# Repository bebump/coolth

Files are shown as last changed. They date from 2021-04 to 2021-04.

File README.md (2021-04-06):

# Bebump Coolth fan controller

Bebump Coolth is a Windows utility that can dynamically control 4 fans
connected to an Arduino Nano.

System diagram

The code and build instructions for the Arduino part are also shared in this
repository. That includes a PCB and 3D printable enclosure if you want to make
it nice.

# Getting started

## Setting up your Arduino

Looking at the wiring diagram in the picture up top, you can quickly assemble
a working prototype using a breadboard.

You need to program the Nano board with the source file in
`arduino_nano/fan_controller.ino`.

If you want you can set persistent fan speeds stored on the Arduino by sending
the following command to it over serial.

    c 2 60 60 60 60

Where the last four `0 <=` integers <= `255`  are the duty cycles for the four
fans. During active operation the PC control software can dynamically overrule
these values. In case the PC software is not running, or communication fails
for more than 3 seconds the Arduino will go back to these persistent values.

## Installing the PC control software

You can download a Windows installer from the releases section. You have the
option to select automatic launch upon Windows startup from the installer.

After launching Bebump Coolth the program will scan the available COM ports
and find the programmed Arduino. It remembers the right COM port, so next time
it will open the same port first.

Everyting can be configured from the GUI and using the program should be
self-explanatory after a bit of experimentation.

The program must run to keep controlling your fans. If you minimize the
application it will become a background process and it will sit on the taskbar
notification area consuming next to no resources.

# Building the PC control software

## The standard way

* Visual Studio 2017 (C# and C++)
* CMake 3.15+

You can use these to build every binary artifact. You have to build
`temperature_reader/temperature_reader.sln` and the `bebump_coolth` target of
`CMakeLists.txt`.

## The completely automatic way

If you want, you can run `scripts/build_everything.py` which will probably do
everything for you from a completely clean checkout. In this case, you also
need

* Python 3.6+

Running the script file will ask you to specify the build output directory (or
use default). Then it will try to find your Visual Studio installation, and
CMake (should be available on your PATH), and then try to build everything.

Worked on my machine.

## Creating the installer

If you choose the automatic way, there will be a bunch of files in the build
output directory.

If you have 

* InnoSetup 6.1.2

you can double click and run the `coolth.iss` file from the build output
directory, press the green play button, and you will have your own installer.

# Building a nicer controller hardware

If you don't want a fire hazard lying around or inside your computer, you may
want to build a proper device with a PCB and 3D printed enclosure.

You can order a PCB by sending the files in `arduino_nano/gerber` to a PCB
manufacturer.

Fan controller PCB

You need to solder the folling components on the PCB.

* 4x Molex 47053-1000 connector
* 1x 5.08 mm PCB terminal block
* 2.54 mm pin headers for connecting the Arduino Nano

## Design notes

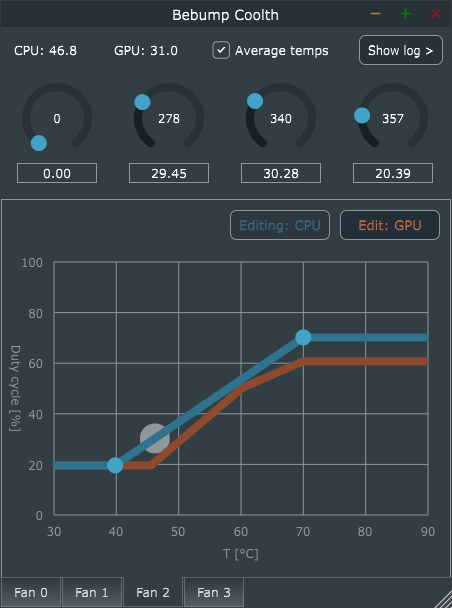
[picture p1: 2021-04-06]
docs/img/coolth_screenshot.png

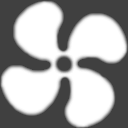
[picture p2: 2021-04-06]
resources/systray.png

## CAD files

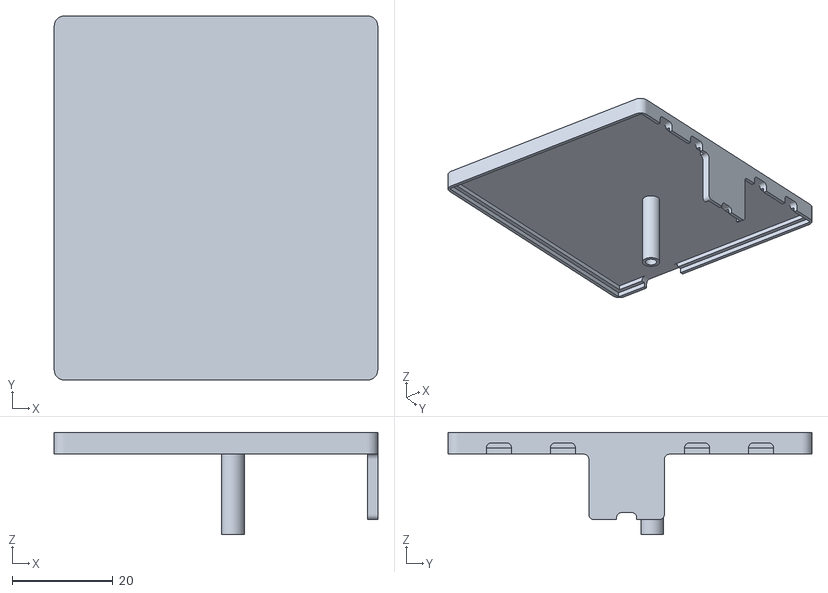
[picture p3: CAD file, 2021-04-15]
arduino_nano/enclosure/enclosure_top.stl
64.3 x 72.3 x 20.4

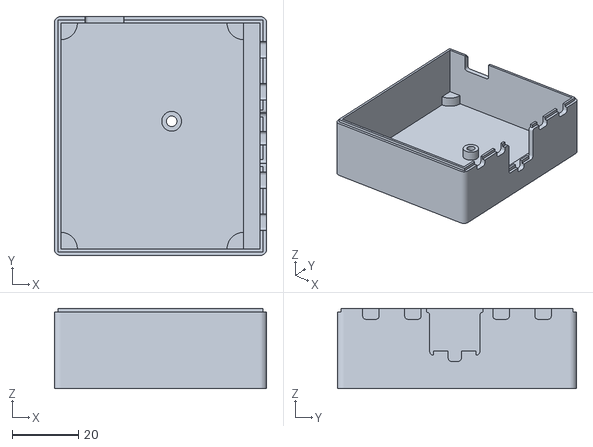
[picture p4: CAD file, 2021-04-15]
arduino_nano/enclosure/enclosure_bottom.stl
64.3 x 72.3 x 24.3

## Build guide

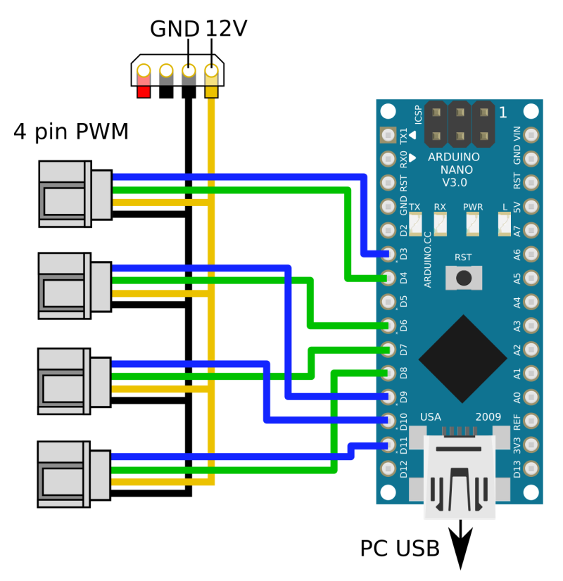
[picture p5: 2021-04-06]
docs/img/wiring_diagram.png

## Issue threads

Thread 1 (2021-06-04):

How to get CPU and GPU temperate data?

Ahmed-Mohiuddin-Shah, 2021-06-04:
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
The CPU and GPU temperature are not showing in the program,
Is there any solution to this?
I have three fans attached to an Arduino Nano.

bebump, 2021-06-04:
Hi Ahmed, I'll do my best to help you, but I'll need more information.

1. Please show me the contents of the log. Click the Log button, like below.
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
2. Did you build the software yourself, or did you install the release?

In any case, please go to

`C:\Users\[YOUR_USERNAME]\AppData\Local\Programs\Bebump Coolth`

and see if you see the file `temperature_reader.exe`. Double click and run it manually, and tell me what the output is.

Ahmed-Mohiuddin-Shah, 2021-06-04:
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

bebump, 2021-06-06:
Thanks for the info.

### New release for seeing at least GPU temps

I have created a new release 0.9.6 which will display and utilize your GPU temperature even if the CPU temperature cannot be read. You can use this to automate your fans based at least on your GPU temperature.

### Further investigation

The root cause of your problem is that `temperature_reader.exe` is unable to read your CPU's temperature. This could be because OpenHardwareMonitor, which is used under the hood, is unable to read the CPU temp.

What CPU model do you have?

You could also verify that this is truly the case by downloading and running Open Hardware Monitor on your machine, and sending me a screenshot like the first image on the following page.

https://openhardwaremonitor.org/

Bebump Coolth already comes with the latest released version of Open Hardware Monitor, so if you have an Intel 11 series CPU that could be a problem. But seeing the screenshot, maybe I can find a workaround or maybe switch to Libre Hardware Monitor.

Ahmed-Mohiuddin-Shah, 2021-06-06:
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
The software is reading the GPU temperature correctly now.
Only CPU temp is not being shown now.
I have installed and opened Open Hardware Monitor and it is detecting CPU Temperature correctly.
My System specs:
core i5 650
nvidia gtx 650
8gb ram
hp oem system

What else could be the problem?
Thanks for the quick responses.

bebump, 2021-06-06:
The screenshot was helpful. I can see you have reported CPU core temperatures, just not a CPU package temperature.

I released a new version (0.9.7) which will use the CPU Core 1 temperature in case there is no package temperature.

Ahmed-Mohiuddin-Shah, 2021-06-06:
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

It is now reading the temperature of the CPU but the CPU reading gets stuck at the reading it started with.
rest of the program is working correctly.

Sorry for late response I was out for work.

bebump, 2021-06-06:
Thank you for the feedback. I can see the issue, and hopefully I fixed it with release 0.9.8.

Ahmed-Mohiuddin-Shah, 2021-06-06:
.exe file is not available in 0.9.8 release

bebump, 2021-06-06:
The number of things that can go wrong. I added the file.

Ahmed-Mohiuddin-Shah, 2021-06-06:
1.   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
Yes! It is working now.
Thank you for helping me.

2.  If in the future if I have any issue should I post in this thread or start new issue?

3.  I like your software. it is very simple and easy to use. You should upload some videos of your software on YouTube. I am sure people will like it. I am making a PowerMac g5 mod case and I will be uploading videos of it so I will make sure to guide people towards your program. Developers like you should be given more recognition.

4. Just one more question is it possible to add HDD0 and HDD1?

bebump, 2021-06-07:
Thank you for the kind words. I'll be closing this issue, please open a new one for future, unrelated issues.

I'll keep the HDD0 feature request in mind, although I can't promise when I might be getting around to implementing it.

UMCURA, 2023-07-29:
Hello, I have problems with the temperature of the GPU, it appears from time to time, but most of the time it does not appear in the program and the operation is wrong. I only have a fan connected, I'm testing it. I have tested the 4 versions and the same problem. What could be happening?. Thank you so much.

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

Closed 2021-06-07.

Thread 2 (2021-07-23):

How to change PWM Frequency?

Ahmed-Mohiuddin-Shah, 2021-07-23:
Is there a way to change to PWM frequency so that my fans don`t make a whining noise.
At slow RPM they create a whining noise which goes away when they are at full speed.
Is there a way where I can change the PWM frequency through the Arduino sketch?

bebump, 2021-07-24:
The PWM frequency is determined by applying various dividers to the 16 MHz clock rate. You can change these divider values in the sketch.

It's worth noting that some of these dividers will also affect the time measurement, so it can mess with the RPM measurement functionality.

You can experiment with it though, just remember, that modifying some related dividers will make the software display incorrect RPM values, and there isn't an easy way around it. It won't affect the behavior of the fans though, so your fans will be controlled correctly, it will be just the displayed values that may be incorrect.

https://www.etechnophiles.com/how-to-change-the-pwm-frequency-of-arduino-nano/

E.g. adding the line `TCCR2B = TCCR2B & B11111000 | B00000001;` somewhere in the beginning of the sketch will raise some PWM frequencies to 31 kHz.

That's as much as I remember from years back. I am using high quality PWM fans which aren't affected by the PWM signal's frequency, because they generate the motor driving signals internally, so I just left things on default in the Arduino sketch.

Ahmed-Mohiuddin-Shah, 2021-07-25:
Thank you. The whine is gone.
I just added the following two line in the setup to change the PWM frequency for pins 3, 5, 6.

TCCR2B = TCCR2B & B11111000 | B00000001;
TCCR0B = TCCR0B & B11111000 | B00000001;

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

I am using pins 3, 5, 6 as those are the pins my fans are attached to. My fans are two wire DC fans so they whine with the default PWM.

If some one else is having Whining Issue and is using the default sketch and schematic then add the following two lines:

TCCR2B = TCCR2B & B11111000 | B00000001;
TCCR1B = TCCR1B & B11111000 | B00000001;

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

Thank you for your help.

Ahmed-Mohiuddin-Shah, 2021-07-27:
UPDATE:
The program was having trouble connecting to the Arduino after adding the lines.

I have now changed the location of the line and the problem is not occurring now.

I removed the following two line in the setup and added them in void loop() before the analogWrite to change the PWM frequency for pins 3, 5, 6.

TCCR2B = TCCR2B & B11111000 | B00000001;
TCCR0B = TCCR0B & B11111000 | B00000001;
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

If some one is using the default sketch and schematic then add the following two lines:

TCCR2B = TCCR2B & B11111000 | B00000001;
TCCR1B = TCCR1B & B11111000 | B00000001;
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

I will update in two days if there are any other issues. If there are none the i will close the issue.

Ahmed-Mohiuddin-Shah, 2021-08-03:
I had no issues. I am closing the issue.

Closed 2021-08-03.

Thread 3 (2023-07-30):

Errors in GPU temperatures.

UMCURA, 2023-07-30:
Hello, I have problems with the temperature of the GPU, it appears from time to time, but most of the time it does not appear in the program and the operation is wrong. I only have a fan connected, I'm testing it. I have tested the 4 versions and the same problem. What could be happening?. Thank you so much.

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

UMCURA, 2023-07-30:
News. Tested on another PC with a Xeon and same O.S. It works perfect. Great since that's where I want to install it. The only thing I see is that the 'Temperature_Reader.exe' gives the data without decimals, none. Maybe that's the problem on this other PC where I started testing it? It has an AMD Ryzen.

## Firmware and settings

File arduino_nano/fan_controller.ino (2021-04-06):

/*
Copyright 2016 Attila Szarvas

Licensed under the Apache License, Version 2.0 (the "License");
you may not use this file except in compliance with the License.
You may obtain a copy of the License at

    http://www.apache.org/licenses/LICENSE-2.0

Unless required by applicable law or agreed to in writing, software
distributed under the License is distributed on an "AS IS" BASIS,
WITHOUT WARRANTIES OR CONDITIONS OF ANY KIND, either express or implied.
See the License for the specific language governing permissions and
limitations under the License.
*/


#include <EEPROM.h>

const int kFan0PwmPin = 3;
const int kFan1PwmPin = 9;
const int kFan2PwmPin = 10;
const int kFan3PwmPin = 11;

const int kFan0RpmPin = 4;
const int kFan1RpmPin = 6;
const int kFan2RpmPin = 7;
const int kFan3RpmPin = 8;

void setup() {
  Serial.begin(19200);

  pinMode(kFan0RpmPin, INPUT_PULLUP); 
  pinMode(kFan1RpmPin, INPUT_PULLUP);
  pinMode(kFan2RpmPin, INPUT_PULLUP); 
  pinMode(kFan3RpmPin, INPUT_PULLUP);
}

void emptySerialBuffer() {
  while (Serial.available() > 0) {
    Serial.read();
  }
}

// Returns 1 if command is intercepted
//         0 otherwise
int ReadSerial(int* buffer, const unsigned int length) {
  while (Serial.available() > 0) {
    if (Serial.read() == 'c') {
      Serial.setTimeout(100);
      int i;
      for (i = 0; i < length; ++i) {
        buffer[i] = Serial.parseInt();
      }

      // We want to respond quickly to duty cycle commands
      // So if there is a long queue of such commands, we 
      // discard the old ones
      emptySerialBuffer();
      return 1;
    }
  }
  
  return 0;
}

// This affects the minimum measurable RPM
// Non-rotating fans will cause twice this much delay per reading
const unsigned long kPwmReadTimeout = 300000;

unsigned long ReadRpm(const int pin) {
  digitalWrite(pin, HIGH);
  delay(5);
  
  // Intel compliant PWM fans generate 2 pulses per cycle
  const unsigned long period_width = 60000000/2;
  unsigned long cycle_width = pulseIn(pin, LOW, kPwmReadTimeout) + pulseIn(pin, HIGH, kPwmReadTimeout);
  
  if (cycle_width == 0) {
    return 0;
  }
  
  return period_width / cycle_width;
}

int dutycycle_command_age = 0;
int fan_0_dutycycle;
int fan_1_dutycycle;
int fan_2_dutycycle;
int fan_3_dutycycle;

void loop() {
  dutycycle_command_age += 1;
  
  const int kCommandLength = 5;
  int command[kCommandLength];
  
  const int kCommandSetDutycycle = 1;
  const int kCommandSetDefaultDutycycle = 2;
  
  unsigned int rpm0, rpm1, rpm2, rpm3;

  rpm0 = ReadRpm(kFan0RpmPin);
  rpm1 = ReadRpm(kFan1RpmPin);
  rpm2 = ReadRpm(kFan2RpmPin);
  rpm3 = ReadRpm(kFan3RpmPin);
      
  Serial.print(rpm0);
  Serial.print(" ");
  Serial.print(rpm1);
  Serial.print(" ");
  Serial.print(rpm2);
  Serial.print(" ");
  Serial.print(rpm3);
  Serial.print(" ");
  Serial.print(fan_0_dutycycle);
  Serial.print(" ");
  Serial.print(fan_1_dutycycle);
  Serial.print(" ");
  Serial.print(fan_2_dutycycle);
  Serial.print(" ");
  Serial.println(fan_3_dutycycle);

  if (ReadSerial(command, kCommandLength)) {
    switch (command[0]) {
      case kCommandSetDutycycle:
        dutycycle_command_age = 0;
        fan_0_dutycycle = command[1];
        fan_1_dutycycle = command[2];
        fan_2_dutycycle = command[3];
        fan_3_dutycycle = command[4];
        break;
        
      case kCommandSetDefaultDutycycle:
        EEPROM.write(0, command[1]);
        EEPROM.write(1, command[2]);
        EEPROM.write(2, command[3]);
        EEPROM.write(3, command[4]);
        break;
    }
  }
  
  if (dutycycle_command_age > 10) {
    fan_0_dutycycle = EEPROM.read(0);
    fan_1_dutycycle = EEPROM.read(1);
    fan_2_dutycycle = EEPROM.read(2);
    fan_3_dutycycle = EEPROM.read(3);
  }
  
  analogWrite(kFan0PwmPin, fan_0_dutycycle);
  analogWrite(kFan1PwmPin, fan_1_dutycycle);
  analogWrite(kFan2PwmPin, fan_2_dutycycle);
  analogWrite(kFan3PwmPin, fan_3_dutycycle);

  delay(200);
}

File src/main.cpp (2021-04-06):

/*
Copyright (c) 2021 Attila Szarvas <attila.szarvas@gmail.com>

All rights reserved. Use of this source code is governed by the 3-Clause BSD
License that can be found in the LICENSE file.
*/

#include "main_component.h"

#include "BinaryData.h"

class GuiAppApplication : public juce::JUCEApplication {
 public:
  GuiAppApplication() = default;

  const juce::String getApplicationName() override {
    return JUCE_APPLICATION_NAME_STRING;
  }

  const juce::String getApplicationVersion() override {
    return JUCE_APPLICATION_VERSION_STRING;
  }

  bool moreThanOneInstanceAllowed() override { return false; }

  void initialise(const juce::String& command_line) override {
    juce::ignoreUnused(command_line);
    main_window = std::make_unique<MainWindow>(getApplicationName() + " " +
                                               getApplicationVersion());
  }

  void shutdown() override { main_window = nullptr; }

  void systemRequestedQuit() override {
    // This is called when the app is being asked to quit: you can ignore this
    // request and let the app carry on running, or call quit() to allow the app
    // to close.
    quit();
  }

  void anotherInstanceStarted(const juce::String& command_line) override {
    // When another instance of the app is launched while this one is running,
    // this method is invoked, and the command_line parameter tells you what
    // the other instance's command-line arguments were.
    juce::ignoreUnused(command_line);
  }

  struct MySystrayIconComponent : public juce::SystemTrayIconComponent {
   public:
    void mouseUp(const juce::MouseEvent& event) override {
      if (onMouseUp) {
        onMouseUp(event);
      }
    }

    void mouseDoubleClick(const juce::MouseEvent& event) override {
      if (onMouseDoubleClick) {
        onMouseDoubleClick(event);
      }
    }

    std::function<void(const juce::MouseEvent&)> onMouseUp;
    std::function<void(const juce::MouseEvent&)> onMouseDoubleClick;
  };

  //===========================================================================
  /*
      This class implements the desktop window that contains an instance of
      our MainComponent class.
  */
  class MainWindow : public juce::DocumentWindow {
   public:
    explicit MainWindow(juce::String name)
        : DocumentWindow(
              name,
              juce::Desktop::getInstance().getDefaultLookAndFeel().findColour(
                  ResizableWindow::backgroundColourId),
              DocumentWindow::closeButton | DocumentWindow::minimiseButton) {
      setContentOwned(new MainComponent(), true);

#if JUCE_IOS || JUCE_ANDROID
      setFullScreen(true);
#else
      setResizable(false, true);
      centreWithSize(getWidth(), getHeight());
#endif

      auto systray_image = juce::ImageFileFormat::loadFrom(
          BinaryData::systray_png, BinaryData::systray_pngSize);
      systray_component_.setIconImage(systray_image, systray_image);
      systray_component_.onMouseUp = [this](const juce::MouseEvent& event) {
        const auto cursor_position_float = juce::Desktop::getInstance()
                                               .getMainMouseSource()
                                               .getScreenPosition();
        addToDesktop();
        toFront(true);
      };
      removeFromDesktop();
      setVisible(true);
    }

    void closeButtonPressed() override {
      // This is called when the user tries to close this window. Here, we'll
      // just ask the app to quit when this happens, but you can change this to
      // do whatever you need.
      JUCEApplication::getInstance()->systemRequestedQuit();
    }

    virtual void minimiseButtonPressed() override { removeFromDesktop(); }

    /* Note: Be careful if you override any DocumentWindow methods - the base
       class uses a lot of them, so by overriding you might break its
       functionality. It's best to do all your work in your content component
       instead, but if you really have to override any DocumentWindow methods,
       make sure your subclass also calls the superclass's method.
    */

   private:
    MySystrayIconComponent systray_component_;

    JUCE_DECLARE_NON_COPYABLE_WITH_LEAK_DETECTOR(MainWindow)
  };

 private:
  std::unique_ptr<MainWindow> main_window;
};

//==============================================================================
// This macro generates the main() routine that launches the app.
START_JUCE_APPLICATION(GuiAppApplication)
